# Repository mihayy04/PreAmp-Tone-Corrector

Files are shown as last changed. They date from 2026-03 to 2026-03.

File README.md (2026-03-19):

# Audio Preamplifier & Tone Corrector PCB 🎛️

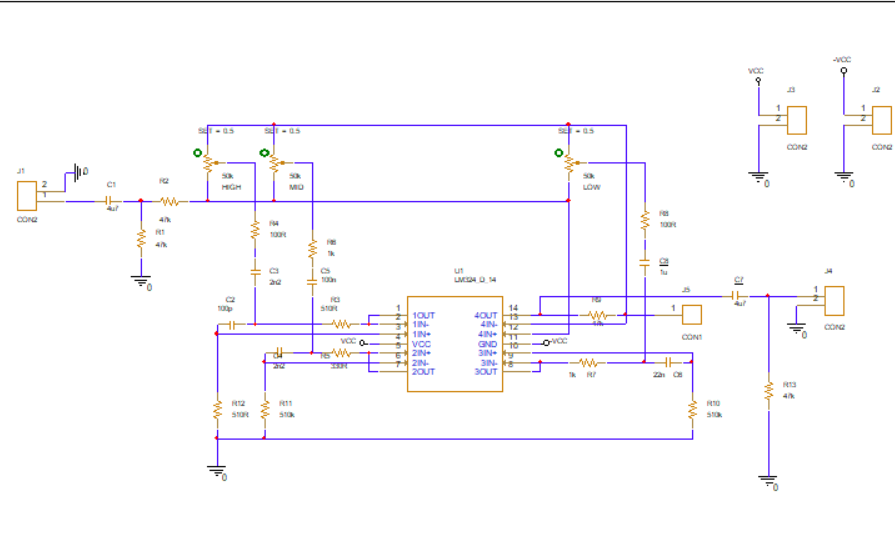
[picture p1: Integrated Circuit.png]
Integrated Circuit Render


## 📌 Project Overview
This repository contains the complete hardware design for an audio preamplifier featuring a dual-band tone corrector and an integrated linear power supply. The entire project—from schematic capture and SPICE simulations to PCB layout—was developed using **Cadence OrCAD**.

The circuit is built using discrete components and is designed to provide high-quality audio signal amplification with precise control over low and high frequencies[cite: 309, 313].

## 🚀 Key Features
* **Active Tone Control:** Independent attenuation and amplification (20dB) for bass (<500Hz) and treble (>1kHz) frequencies using an RC feedback network[cite: 311, 314, 327].
* **Discrete Analog Design:** The audio path and power regulation are built around classic Bipolar Junction Transistors (BC109C, BC107, BD135).
* **Integrated Linear Power Supply:** An on-board 25V regulated power supply featuring a series pass transistor and an error amplifier, ensuring a stable and low-noise power delivery for the audio stages.
* **Manufacturing Ready:** Includes full documentation, BOM, and manufacturing tables for immediate PCB fabrication.

## 📂 Repository Structure
The project files are organized to reflect a standard hardware engineering workflow:

* `📂 Bill of materials/` - Comprehensive BOM listing all components required for assembly.
* `📂 Data Sheet/` - Technical datasheets for the active and passive components used in the design.
* `📂 Layout/` - OrCAD PCB Editor files containing the board routing and layout data.
* `📂 Project docs/` - Detailed technical documentation, including mathematical component sizing and design choices.
* `📂 Schematics/` - OrCAD Capture schematic files for the preamplifier and power supply modules.
* `📂 Simulations/` - PSpice simulation results, including:
  * DC Operating Point (Bias) analysis.
  * Transient response analysis.
  * AC Sweep (Frequency response / Bode plots) demonstrating the tone correction curves.
* `📄 PCB_Manufacturing_Table_2026.docx` - Manufacturing specifics and tolerances.

## 💻 Software Stack
* **Cadence OrCAD Capture** (Schematics)
* **Cadence OrCAD PCB Editor** (Layout)
* **OrCAD PSpice** (Analog Circuit Simulation)

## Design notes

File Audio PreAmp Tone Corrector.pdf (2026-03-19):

### Capitolul 3

### PREAMPLIFICATOR AUDIO CORECTOR DE TON

În acest capitol este proiectat un preamplificator audio cu posibilitatea corecţiei frecvenţelor joase şi a celor înalte. Preamplificatorul audio corector de ton este compus din două etaje de amplificare conectate prin intermediul unei reţele de reacţie. Prin introducerea unor componente variabile în reţeaua de reacţie se pot amplifica sau atenua frecvenţele joase respectiv frecvenţele înalte.

### 3.1 TEMA DE PROIECTARE

Tema de proiectare se referă la proiectarea unui preamplificator audio corector de ton care să fie realizat cu tranzistoare bipolare. Corecţia de ton se referă la corecţia frecvenţelor joase şi anume a frecvenţelor mai mici ca 500Hz şi a frecvenţelor înalte respectiv mai mari ca 1KHz.
Etajul este compus din două amplificatoare, respectiv amplificatorul de intrare şi amplificatorul de ieşire, cuplate prin intermediul reţelei de reacţie de tipul RC. Reţeaua de reacţie este constituită din două filtre cu elemente pasive RC de joasă, respectiv înaltă frecvenţă în care anumite rezistenţe sunt variabile fapt ce permite amplificarea sau atenuarea frecvenţelor care sunt în banda de trecere a filtrelor RC. Amplificatorul de intrare şi cel de ieşire sunt alimentate din sursa de alimentare comună.

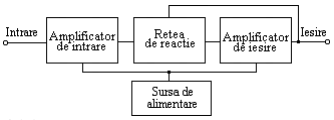
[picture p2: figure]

Figura 3.1-1. Schema bloc a preamplificatorului audio corector de ton

Preamplificator audio corector de ton | 71

### 3.2 SETURI DE DATE DE INTRARE

Principalii parametri ai preamplificatorului audio corector de ton sunt: Rezistenţa de intrare Ri (K )
Rezistenţa de ieşire Ro ( )
Corecţia minimă a frecvenţelor joase şi a frecvenţelor înalte 20dB

Sursa de alimentare va asigura următorii parametri:
Curentul nominal maxim I0M (mA)
Rezistenţa de ieşire maximă R0M ( )

Coeficientul de stabilizare
S
V

V
S

I
0min
0

0

Tensiunea de alimentare este 220Vac 10%

Tabelul 3.2-1. Seturi de date de intrare pentru proiectare
Nr. | Preamplificator corector de ton | Sursa de alimentare
Ri (M ) | Ro ( ) | Av (-) | Aî,j ( dB) | I0M (mA) | R0M ( ) | S0min (-)
1 | 2 | 150 | 5 | 20 | 10 | 3 | 2
2 | 2 | 150 | 5 | 18 | 10 | 4 | 3
3 | 2 | 150 | 5 | 16 | 10 | 5 | 4
4 | 2 | 150 | 5 | 14 | 10 | 6 | 5
5 | 2 | 150 | 5 | 12 | 10 | 7 | 6
6 | 2 | 150 | 4 | 20 | 10 | 3 | 2
7 | 2 | 150 | 4 | 18 | 10 | 4 | 3
8 | 2 | 150 | 4 | 16 | 10 | 5 | 4
9 | 2 | 150 | 4 | 14 | 10 | 6 | 5
10 | 2 | 150 | 4 | 12 | 10 | 7 | 6
11 | 2 | 150 | 3 | 20 | 10 | 3 | 2
12 | 2 | 150 | 3 | 18 | 10 | 4 | 3
13 | 2 | 150 | 3 | 16 | 10 | 5 | 4
14 | 2 | 150 | 3 | 14 | 10 | 6 | 5
15 | 2 | 150 | 3 | 12 | 10 | 7 | 6
16 | 2 | 150 | 2 | 20 | 10 | 3 | 2
17 | 2 | 150 | 2 | 18 | 10 | 4 | 3
18 | 2 | 150 | 2 | 16 | 10 | 5 | 4
19 | 2 | 150 | 2 | 14 | 10 | 6 | 5
20 | 2 | 150 | 2 | 12 | 10 | 7 | 6

72 | Proiectarea circuitelor electronice de audiofrecvenţă

Setul de date utilizate pentru exemplificare

Pentru proiectarea etajelor amplificatorului audio de putere a fost utilizat setul de parametri următori:

Tabelul 3.2-2. Setul de date utilizate pentru exemplificare
Nr. | Preamplificator corector de ton | Sursa de alimentare
Ri (M ) | Ro ( ) | Av (-) | Aî,j ( dB) | I0M (mA) | R0M ( ) | S0min (-)
1 | 2 | 150 | 5 | 20 | 10 | 3 | 2

### 3.3 SCHEMA ELECTRONICĂ

Conform schemei de principiu primul etaj este amplificatorul de intrare care asigură separarea reţelei de reacţie de etajele anterioare. În acest scop etajul de intrare este realizat cu tranzistorul T1 şi este de tip colector comun cu bootstrap la intrare asigurând o impedanţă mare de intrare şi mică de ieşire.
Reţeaua de reacţie este de tip RC cu elemente rezistive variabile P1 şi P2 care asigură reglarea frecvenţelor înalte şi joase.
Amplificatorul de ieşire este realizat cu tranzistoarele T2 şi T3 în conexiune emitor comun respectiv colector comun cuplate galvanic.
Primul etaj realizat cu T2 este destinat realizării unei amplificări de tensiune în buclă deschisă suficient de mare iar etajul realizat cu T3 este repetor pe emitor şi asigură o rezistenţă de ieşire mică. Cele două etaje realizează un amplificator inversor, astfel reţeaua de reacţie este plasată între intrarea şi ieşirea acestui amplificator de ieşire.

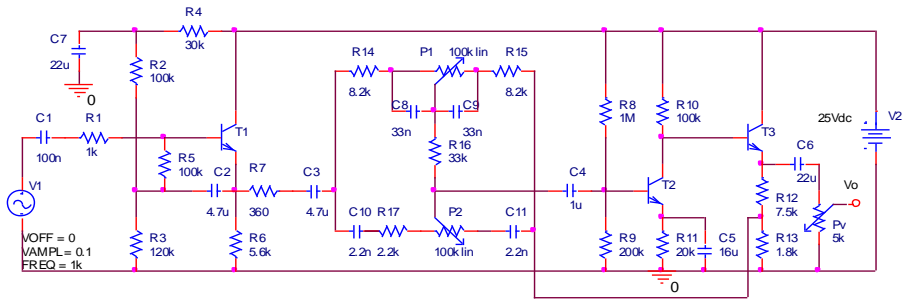
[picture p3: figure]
100k lin; 25Vdc; FREQ = 1k; VAMPL = 0.1; VOFF = 0

Figura 3.3-1. Schema electronică

Preamplificator audio corector de ton | 73

### 3.4 DIMENSIONAREA REŢELEI DE REACŢIE

Elementele de atenuare pozitivă sau negativă pentru frecvenţele înalte respectiv joase formează reţeaua de reacţie negativă.
Pentru o bună înţelegere a principiului de funcţionare a corecţiei amplitudinii pe anumite domenii de frecvenţă considerăm etajele amplificatoare echivalente cu circuite operaţionale care au conectate impedanţele echivalente ca în Figura 3.4-1..

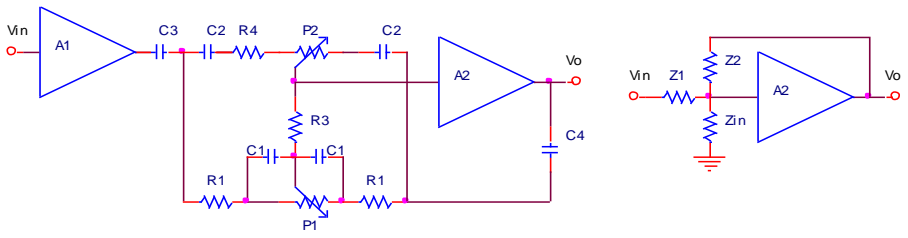
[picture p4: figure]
Zin; Vin

a) b)
Figura 3.4-1. Schema echivalentă a preamplificatorului audio corector de ton cu reţeaua de reacţie a) şi schema echivalentă simplificată b)

A1 reprezintă preamplificatorul de intrare iar A2 reprezintă amplificatorul de ieşire. Reţeaua de reacţie prevăzută cu potenţiometrele P1 şi P2 este desenată simplificat

în Figura 3.4-1. b), amplificarea etajului fiind data de raportul impedanţelor
Z

Z

1

2

Calculul reţelei de reacţie se face pentru circuitele echivalente la joasă şi înaltă frecvenţă.

Circuitul echivalent pentru înaltă frecvenţă

(1-a)P2

1k

R1 | R1

R1'

C2

R1' | R1'

aP2

1k

R4 | C2

R1'

R1

aP2

1k

(1-a)P2

1k

C2 | R4 | C2

R3

2R3 | 2R3

R1

Figura 3.4-2. Circuitul echivalent al reţelei de reacţie pentru înaltă frecvenţă

Pentru înaltă frecvenţă circuitul echivalent este prezentat în Figura 3.4-2., iar funcţia de transfer este:

F(p) =
Z

Z

1

2
= k
(1 | )(1 | )
(1 | )(1 | )
| 3 | 4
1 | 2
p t | p t
p t | p t

74 | Proiectarea circuitelor electronice de audiofrecvenţă
k = 1 | R1’ = R1 + 2R3
t1 = aR2C2 | t2 = [R1’ + (1-a)R2]C2
t3 = R1’C2 | t4 = R2C2

Curba de atenuare maximă se obţine pentru a = 0 şi rezultă:

t1 = 02 | t2 = [R1’ + R2]C2
t3 = (R1’+ aR2)C2 | t4 = (1-a)R2C2

Se alege P2 de 100K .
Pentru ca interferenţa celor două circuite să fie minimă se impune ca R1 | P2 şi
rezultă R1 | 10K .
R1’ s-a obţinut prin transformarea stelei R3, R1, R1 şi s-a neglijat rezistenţa ce apare între intrarea şi ieşirea lui A2, considerând că amplificatoarele A1 şi A2 au impedanţa de ieşire foarte mică.

Se alege f2 = 500Hz şi rezultă t2 = (R1’+R2)C2 = 3,2 10⁻⁴
s

Se alege f4 = 700Hz şi rezultă t4 = R2C2 2,3 10⁻⁴
s

Rezultă şi se adoptă C2 = 2,2nF.

Se alege f3 = 1KHz şi rezultă t3 = R1’C2 = 1,6 10⁻⁴
s,
R1’ = 72K .

Punctul f3 = 1KHz s-a dedus grafic pe caracteristica Bode astfel încât atenuarea teoretică de –20dB se produce la 15KHz.

Se alege R1 = 8,2K şi R3 =
2

1

'
R1 R
= 31,9K .

Se adoptă R3 = 33K .

Curba de ridicare minimă se obţine pentru a = 1 şi rezultă:
t1 = R2C2 | t2 = R1’ C2
t3 = (R1’+R2)C2 | t4 = R4C2

Curba de ridicare va fi simetrică cu cea de coborâre până la f4, când factorul de transfer devine constant.
Astfel, se explică rolul rezistenţei R4 care menţine al doilea pol din funcţia de transfer, chiar pentru a = 1 asigurându-se stabilitatea.
Se apreciază din considerente practice confirmate experimental că f4 | 30Hz | t4

= (2 f4)

-1
= 5,3 | R4 =
C

t

2

4
= 2,4K

Preamplificator audio corector de ton | 75

Circuitul echivalent pentru joasă frecvenţă

C1

R1 | aP1 | (1-a)P1 | R1

C1

Figura 3.4-3. Circuitul echivalent pentru joasă frecvenţă

Pentru circuitul echivalent la joasă frecvenţă funcţia de transfer are forma:

F(p) =
Z

Z

1

2
= k
(1 | )(1 | )
(1 | )(1 | )
| 3 | 4
1 | 2
p t | p t
p t | p t
Se alege | P1 = nR1 = 100K | n 12

Curba de atenuare maximă se obţine pentru a = 0

k = | 1 n

1
| ,
t1 = 0 | | t2 = n R1 C2
t3 = 0 | | t4 =
n 1

n
R1 C2

Curba de ridicare maximă se obţine pentru a = 1 k = n + 1,
t1 = | n 1 n
| R1 C1 | t2 = 0
t3 = n R1 C1 | t4 = 0
Se alege | f2 = 50Hz | t2 = 3,2s
| C1
| R

t

1

2
12

= 32nF Se adoptă C1 = 32nF.

Reţeaua pentru joasă frecvenţă începe să lucreze sub frecvenţa de aproximativ 500Hz. La 50Hz ridicarea este de 20log(n +1)=22dB iar atenuarea de –22dB.

### 3.5 PROIECTAREA AMPLIFICATORULUI DE IEŞIRE

Amplificatorul de ieşire A2 este realizat cu T2 şi T3 iar pentru respectarea condiţiei de semnal mic trebuie ca semnalele alternative să fie mult mai mici ca tensiunea de alimentare. O tensiune de alimentare mare implică şi rezistenţe de polarizare de valori mari şi deci impedanţă mare de intrare. Din aceste considerente se alege Ec = 25V stabilizată. Distorsiunile se vor măsura experimental şi se va modifica PSFul dacă este cazul.

76 | Proiectarea circuitelor electronice de audiofrecvenţă
1. Se alege PSFul pentru tranzistorul T2

Curentul de colector ICT2 =0,1mA şi tensiunea colector-emitor VCE2 10V

Se alege raportul
R

R

11

10
10
Se alege VR10 | 10V | Se adoptă R10 = 100K şi R11 =20 K
2. Se alege PSFul pentru tranzistorul T3

Curentul de colector ICT3 =1,5mA şi tensiunea colector-emitor VCE3 = 10V

R12 + R13
I
E | V
| C
C | CE

3

3
=
1,5mA

15V
= 10K
3. Alegerea tranzistoarelor

Se aleg tranzistoarele de tip BC109C cu următoarele valori limită absolute:
VCE0 =25V | IC = 100mA | IB = 50mA
Ptot = 300mW | Tj = 175 C
şi caracteristicile statice:
h21E = 270 | VCEsat | 0,2V | VBEsat | 0,8V
4. Dimensionarea rezistenţelor R12, R13

IB,T3 =
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
1,5mA
= 5,5 A

Acest curent poate fi neglijat în raport cu IC2. În acest caz tensiunea pe R10 este: VR10 = R10 IC2 = 100K 0,1mA = 10V
VR12+R13 = EC – VR10 – VBE2 = 25 – 10 - 0,6 = 14,4V
În reţeaua de reacţie s-a neglijat rezistenţa care apare între intrarea şi ieşirea amplificatorului de ieşire A2. Valoarea acestei rezistenţe este:

Rp =
| R
R | R R

3

1 3

2
1 | 2
18K | R0,A2

Se alege R13 = 1,8K şi se calculează R12:

R12 + R13 =
I

V

C

R | R
| 3
12 | 13
=
mA

V
1,5

14,4
= 9,3K

R12 = 9,3K - 1,8K = 7,5K .

5. Calculul divizorului de bază pentru tranzistorul T2

Curentul prin divizorul de polarizare a bazei tranzistorului T2 este:

IB2 =
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
0,1mA
= 0,37 A

Preamplificator audio corector de ton | 77

Deoarece impedanţa de intrare a amplificatorului A2 este dată de impedanţa de intrare în T2, iar aceasta este aproximativ R9, se alege R9 = 200K .
Tensiunea pe rezistenţa R9 poate fi exprimată astfel:
VR9 = VR11 +VBE2 = 20K | 0,1mA + 0,6V = 2,6V
R | R

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
R8 8R9 = 1,6M

6. Calculul impedanţei de intrare în A2

Parametri dinamici ai tranzistorului T2 sunt:

gm2 = 40 IC2 = 40 0,1 = 4mA/V

h11e,T2 =
| gm2 =
4

270
= 67,5K

Impedanţa de intrare în T2 este:

Zin, T2 = h11e,T2 + h21e,T2 | R11 = 67,5 K + 270 20K | 5,4M

Impedanţa de intrare în T2 este:

Zin, A2 = ( R9 | R8 ) Zin, T2 | 180K | 5,4M | 180K
Această valoare este suficient de mare.
7. Amplificarea în buclă deschisă a etajului realizat cu T2

Atenuarea maximă a circuitului este de aproximativ 10 şi se verifică ca amplificarea fără reacţie să fie suficient de mare:

Av | Av,T2 =
R | h
h | R
g | e
E | S
| 11 2
21 | 2

RS2 este rezistenţa de sarcină a tranzistorului T2:

RS2 = R10 Zin, T3

Zin, T3 = h11e3 + h21e3 (R12 +R13) =
40 1,5mA

270
+ 270 9,3K | 2,5M
RS2 | R10 = 100K
Av | Av,T2 =
K

K
80

270 100
= 338 valoare suficient de mare.
8. Amplificarea în buclă închisă

În poziţia mediană a lui P1 şi P2 se obţine Z1 = Z2, iar amplificarea este:

78 | Proiectarea circuitelor electronice de audiofrecvenţă

Avr

r

1
=
R
R | R
| 13
12 | 13
=
1,8

7,5 1,8
= 5,17 5

Micşorarea amplificării este compensată de îmbunătăţirea răspunsului tranzitoriu.

9. Dimensionarea condensatorului C5

C5 formează un pol şi un zero, polul fiind plasat la frecvenţă mai mare.

5 =

h

R h
C R
| e
g | e

21 2

11 2
5 11

1

Pentru tranzistorul T2, considerăm pentru uşurinţa calculelor parametri dinamici
aproximativi h11e2 | 100K şi h21e2 | 100.
Din motive de stabilitate se alege polul dat de C5 polul dominant al schemei şi anume f5=10Kz.

C5 =
| h h
f
| e

e

21 2

11 2
5

2

1
= 15,9 F

Se adoptă C5 = 16 F/10V

10. Dimensionarea condensatorului C4

Tot din considerente de stabilitate, se alege polul dat de C4 la o frecvenţă mult mai mică decât cea dată de C5. Se alege f4 = 1Hz 10Hz = f5.

C4 =
2 f
4 Zin,A2

1
=
2 1 180K

1
= 0,88 F

Se alege C4 = 1 F.

### 3.6 PROIECTAREA AMPLIFICATORULUI DE INTRARE

Amplificatorul de intrare este constituit din etajul repetor pe emitor cu bootstrap la intrare realizat cu tranzistorul T1.

1. Stabilirea PSFului

Se alege IC1 = 2mA care este o valoare relativ mare din punct de vedere al zgomotului, dar care asigură curent de bază suficient de mare pentru a fi insensibil la curentul de fugă prin capacitatea de bootstrap C2.
Se alege VCE1 | VR6.
Cunoaştem R6 şi IC1 | VR6 = 5,6K | 2mA = 11,2V

Preamplificator audio corector de ton | 79

VCE1 = EC - VR6 = 13,8V

2. Dimensionarea rezistenţei R5

Tensiunea în baza tranzistorului T1 este:
VBT1 = VBE1 + VR6 = 0,6 + 11,2 = 11,8V Curentul de bază al tranzistorului T1 este:

IBT1 =
h

I

E

C

21 1

1
=
400

2
= 5 A
Din catalog pentru IC1 = 2mA şi VCE1 = 14V se obţine h11e1 | 10K .
Se impune R5 | h11e1 şi se alege R5 = 100K .
VR5 = R5 | IB1 = 100K | 5 A = 0,5V
VR3 = VB1 + VR5 = 11,8 + 0,5 = 12,3V
3. Calculul divizorului de bază

Se alege Id = 20 IB1 = 100 A

R2 + R3 + R4 =
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
= 250K
R3 = | R | R | R
E

V

C

R
2 | 3 | 4

3
= | K
V

V
250
25

12,3
= 123K

Se adoptă R3 = 120K .
Pentru a avea o valoare convenabilă a condensatorului de filtraj C7 se alege R4 = 30K şi R2 = 100K .
4. Dimensionarea condensatorului de filtraj C7

Rezistenţa R4 şi condensatorul C7 decuplează alimentarea circuitului de bază. Pentru o bună decuplare f7 frecvenţa inferioară limită a benzii.

Pentru C7 = 22 F se obţine f7 =
2 C7 R4

1
= 0,24Hz
5. Impedanţa de intrare

Impedanţa de intrare în amplificatorul de intrare şi în preamplificatorul corector de ton este:
Zin = R5 h11e1 + ( ’
+ 1) R6

’
= 1
R h

R

5 11e1

5
= 400
K K

K
100 10

100
= 360

Zin = 9,1 K +360 5,6K = 2M

80 | Proiectarea circuitelor electronice de audiofrecvenţă
6. Dimensionarea condensatoarelor C1, C2

Condensatoarele C1 şi C2 se dimensionează pentru frecvenţe mai mici ca 1Hz. Se

alege C1 = 0,1 F şi se obţine f1 =
| 2 C1Zin
| 1 = 0,79Hz

Pentru C2 se alege f2 = 0,5Hz şi se obţine C2 =
| 2 f 2R5

1
= 3,2 F

Se adoptă C2 = 4,7 F

7. Impedanţa de ieşire a amplificatorului de intrare

Z0,A1
R
Zg | RS | h e

6 '

| | 11 1
| | 1
Se apreciază că impedanţa generatorului este mai mică decât 15K şi pentru cazul cel mai defavorabil se ia Zg = 15K .

Z0,A1

K

K K
5,6
360

15 9
6,6

Se verifică condiţia Z0,A1 = 6,6 Rp = 18K

8. Impedanţa de ieşire a preamplificatorului corector de ton
Z0, pct = | R | R
h
Z | h
| e
g | e
12 | 13
21 3

11 3

Zg = R10
h22e2

1
= 100K 92K = 48K

Considerăm pentru T3 parametri dinamici următori: h11e3 = 10K şi h21e3 = 400

Z0, pct = | K
K | K
9,3
400
| 48 | 10
= 143
9. Dimensionarea potenţiometrului de volum

Se poate face dimensionarea potenţiometrului de volum utilizând condiţia:

Z0, pct | Pv | Zin, AP
Impedanţa de intrare în amplificatorul audio de putere Zin, AP | 39K

Raportul impedanţelor limită este k =
Z

Z

pct

in AP

0,

,
=
143

39K
270

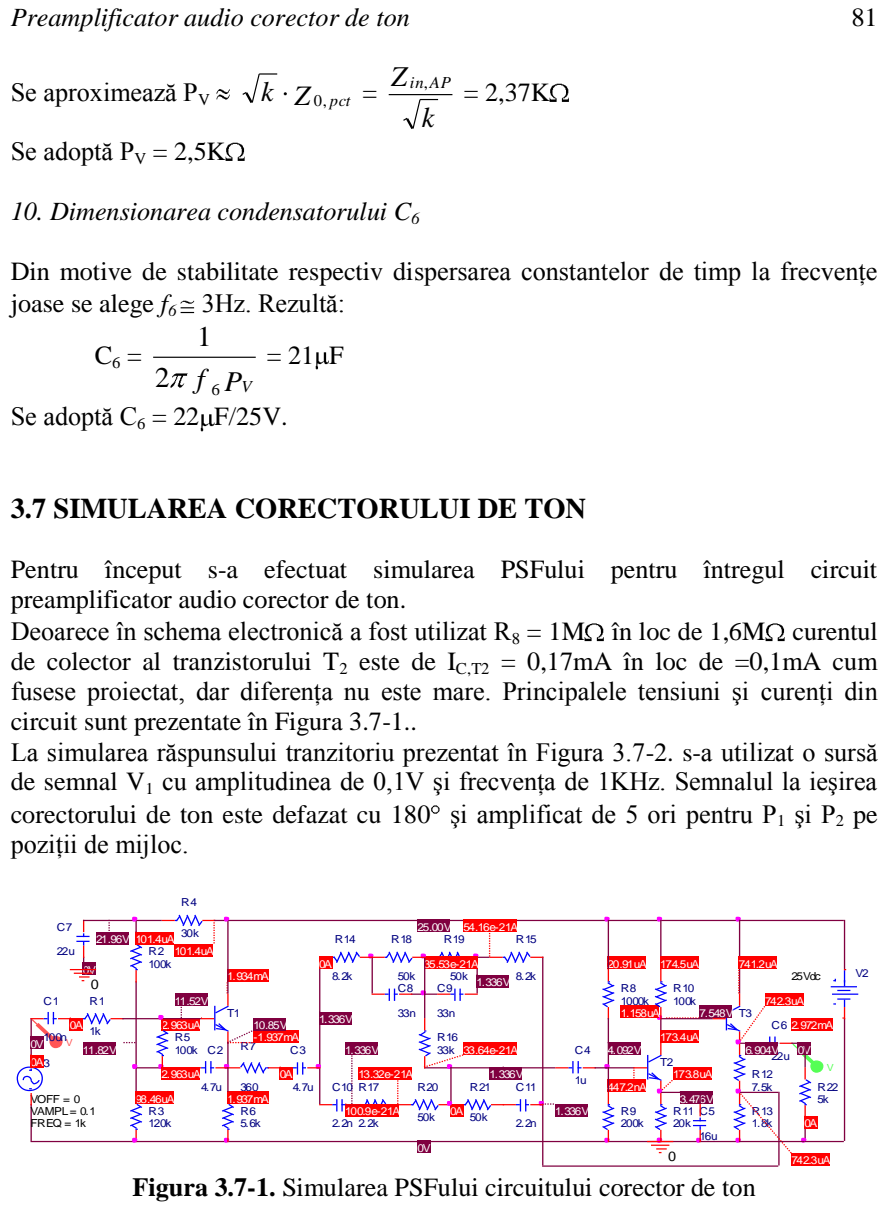
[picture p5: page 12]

Din motive de stabilitate respectiv dispersarea constantelor de timp la frecvenţe

3.7 SIMULAREA CORECTORULUI DE TON

Pentru început s-a efectuat simularea PSFului pentru întregul circuit
preamplificator audio corector de ton.
Deoarece în schema electronică a fost utilizat R8 = 1M în loc de 1,6M curentul
de colector al tranzistorului T2 este de IC,T2 = 0,17mA în loc de =0,1mA cum
fusese proiectat, dar diferenţa nu este mare. Principalele tensiuni şi curenţi din
circuit sunt prezentate în Figura 3.7-1..
La simularea răspunsului tranzitoriu prezentat în Figura 3.7-2. s-a utilizat o sursă
de semnal V1 cu amplitudinea de 0,1V şi frecvenţa de 1KHz. Semnalul la ieşirea
corectorului de ton este defazat cu 180 şi amplificat de 5 ori pentru P1 şi P2 pe
poziţii de mijloc.

Figura 3.7-1. Simularea PSFului circuitului corector de ton

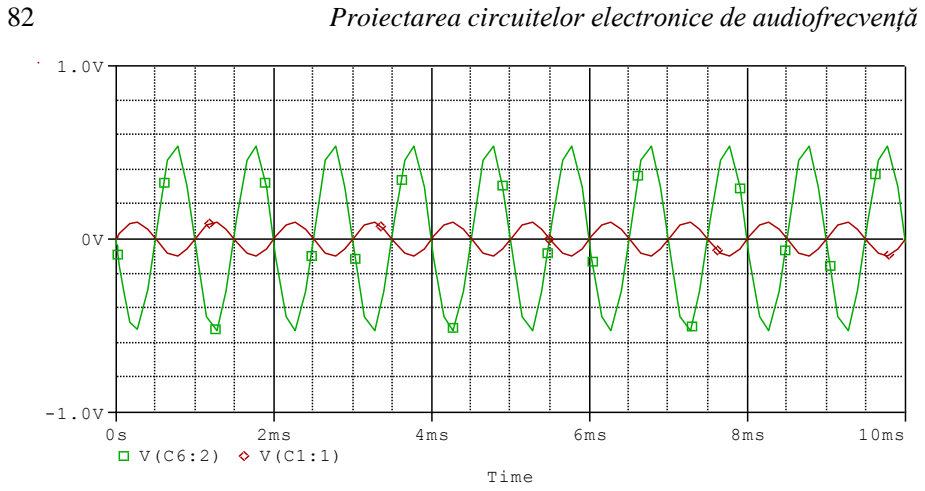
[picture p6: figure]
Proiectarea circuitelor electronice de audiofrecvenţă; Time

Figura 3.7-2. Simularea tranzitorie a circuitului corector de ton

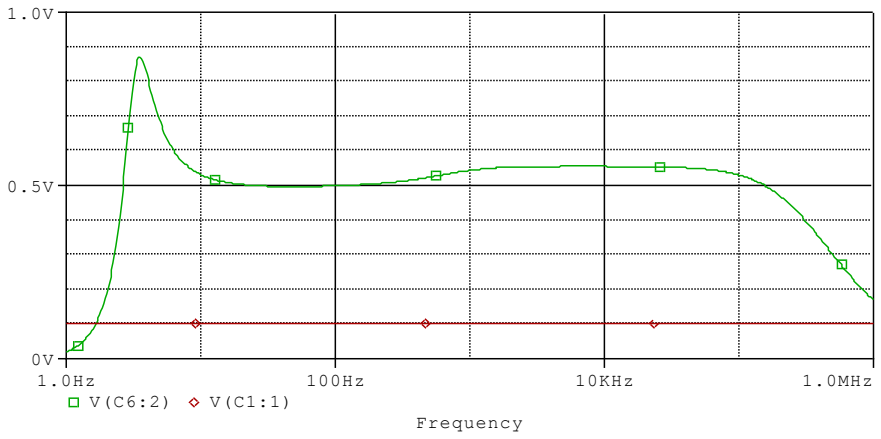
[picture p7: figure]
Frequency; 10KHz; 1.0MHz

Figura 3.7-3. Simularea răspunsului în frecvenţă al corectorului de ton cu P1 şi P2 pe poziţia mediană (R18=50K , R19=50K şi R20=50K , R21=50K )

Simularea răspunsului în frecvenţă pentru P1 şi P2 pe poziţii de mijloc Figura 3.7-
3. ne arată o amplificare de 5 la o amplitudine a semnalului de 0,1V şi răspuns uniform în banda de frecvenţe cu excepţia frecvenţelor joase unde este practic realizată o corecţie fiziologică.
Simulările 3.7-4. 3.7-7. arată accentuarea şi atenuarea frecvenţelor joase şi a celor înalte cu aproximativ 20dB faţă de poziţia mediană de la 0,5V.

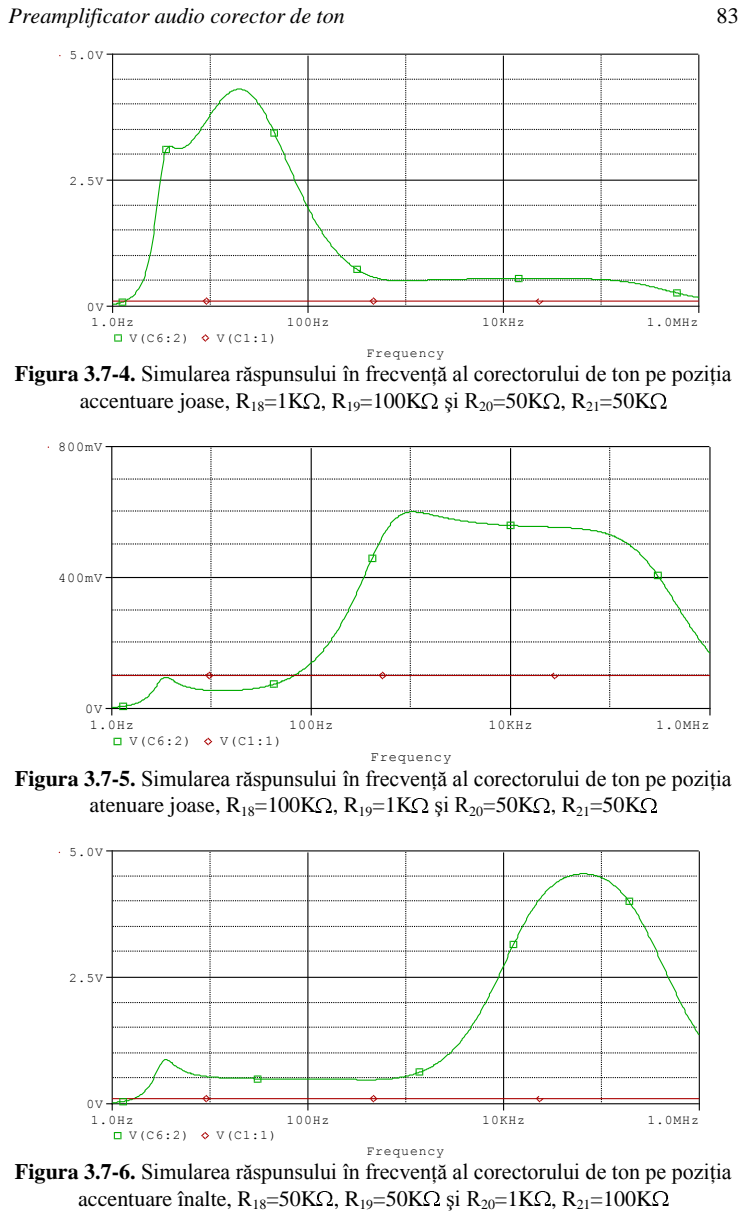
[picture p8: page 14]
Preamplificator audio corector de ton; Frequency; 10KHz; 1.0MHz

Figura 3.7-4. Simularea răspunsului în frecvenţă al corectorului de ton pe poziţia

accentuare joase, R18=1K , R19=100K şi R20=50K , R21=50K

Figura 3.7-5. Simularea răspunsului în frecvenţă al corectorului de ton pe poziţia

atenuare joase, R18=100K , R19=1K şi R20=50K , R21=50K

Figura 3.7-6. Simularea răspunsului în frecvenţă al corectorului de ton pe poziţia

accentuare înalte, R18=50K , R19=50K şi R20=1K , R21=100K

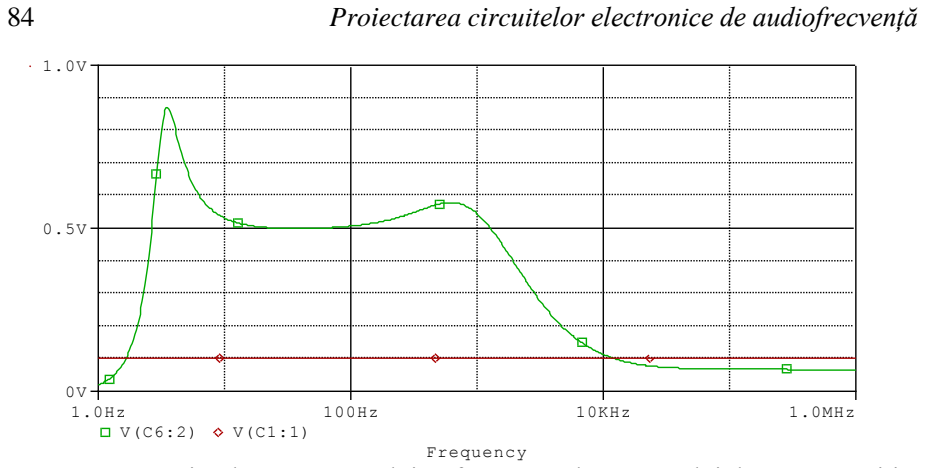
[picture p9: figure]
Proiectarea circuitelor electronice de audiofrecvenţă; Frequency; 10KHz; 1.0MHz

Figura 3.7-7. Simularea răspunsului în frecvenţă al corectorului de ton pe poziţia atenuare înalte, R18=50K , R19=50K şi R20=100K , R21=1K

### 3.8 SURSA DE ALIMENTARE

Alimentarea preamplificatorului audio corector de ton se face utilizând stabilizatorul din Figura 3.8-1. alcătuit dintr-un tranzistor regulator serie T1 şi un amplificator de eroare realizat cu tranzistorul T2. Diodele D1, D2 realizează o prestabilizare a tensiunii de alimentare a amplificatorului de eroare, iar dioda D3 realizează tensiunea de referinţă.
Conform temei de proiectare variaţiile tensiunii de alimentare sunt 10%. Pentru o tensiune medie la ieşirea redresorului VR=30V tensiunea maximă la ieşirea redresorului şi tensiunea minimă la ieşirea redresorului sunt VRM=33V şi VRm=27V.

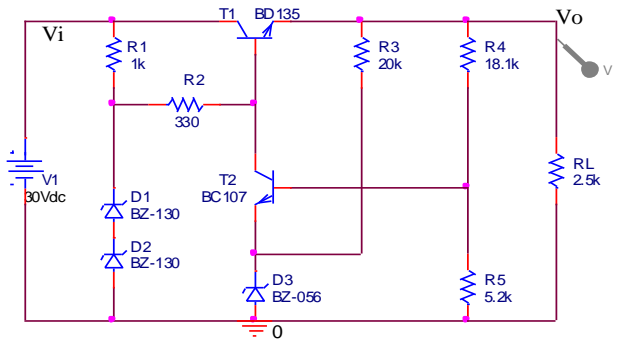
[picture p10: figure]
V1 30Vdc

Figura 3.8-1. Stabilizatorul pentru preamplificatorul audio corector de ton

Curentul de alimentare pentru două canale ale amplificatorului corector de ton cu tranzistoare se estimează la 2x3mA 10mA.
Tensiunea de ieşire a stabilizatorului este de 25Vcc.

Preamplificator audio corector de ton | 85

Proiectarea stabilizatorului

1. Alegerea tranzistorului regulator serie

Se alege tranzistorul T1=BD135 cu următorii parametri:
VCE0 = 80V | IC =1A | Ptot= 12,5W
VCER = 100V | ICM =1,5A | fT = 50MHz
VEB0 = 5V | IB =0,2A | Rthj-C | 10 C
h21E = 50 200 | Tj =150 C
PSFul tranzistorului T1 este IC=10mA, VCE=5V pentru care h21e | 100.
2. Alegerea diodelor stabilizatoareD1, D2

Se aleg diodele D1, D2 = BZ-130 care au următorii parametri:
RS = 0,001 | CJ0 = 1 10⁻¹² | | M = 0,3333
Vj = 0,75 | ISR = 3,997 10⁻⁶ | | BV = 13,05
IBV = 0,1293 | TT = 144,3 10⁻⁹

Curentul maxim prin diodă este IM =
BV

PM
| | = | V

mW
13

100
= 7,7mA, iar pentru

curentul minim se alege Im = 0,5mA IBV = 0,1293mA

Curentul din baza tranzistorului T1 este:

mA mA I
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
21 1

1

Din considerente de stabilitate a PSFului se alege curentul prin R2 mult mai mare ca IB1 respectiv IR2 0,7mA 0,1mA=IB1.

3. Dimensionarea rezistenţei R1

Dimensionarea rezistenţei R1 se face astfel ca la tensiunea de intrare minimă aceasta să asigure funcţionarea diodei zener la Im = 0,5mA IBV = 0,1293mA.

k
I | I | mA | mA

V
R
Z | R

0,84
0,5 | 0,7
| | 27 26
min | 2
| min
1 | , | Se adoptă R1=1K

În condiţiile în care tensiunea de intrare este maximă curentul prin dioda zener nu trebuie să depăşească curentul maxim admisibil.

I | mA | mA
| | K

I
R

V
I
Z | R | R | 7 | 0,7
1

33 26

2 | 2
1

max
max

= 6,3mA

IZ max = 6,3mA IMax adm = 7,7mA.

4. Dimensionarea rezistenţei R2

86 | Proiectarea circuitelor electronice de audiofrecvenţă

R2 =
I
V | V | V | V

R

D | D | BE

2

1 | 2 | 0 | 1
=
0,7

13 13 25 0,7
=
mA

V
0,7

0,3
=428

Se adoptă R2 =330

5. Verificarea puterii disipate de tranzistorul regulator serie T1

Pentru verificarea puterii disipate de T1 în cazul cel mai defavorabil calculăm tensiunea colector-emitor, când prin diodele D1, D2 trece curentul maxim de 7,7mA. În această situaţie tensiunea pe rezistenţa R1 esteVR1=7,7V iar tensiunea pe rezistenţa R2 este VR2=0,7mA 0,33K = 0,23V. Deoarece VCB=VR1+VR2 VCE=VR1+VR2 +VBE=8,63V
Pd = VCE IC = 8,63V 10mA=86,3mW Puterea disipată fără radiator=2W.
6. Alegerea diodei stabilizatoare D3

Se alege dioda D3 = BZ-056 care are următorii parametri:
RS = 0,001 | CJ0 = 1 10⁻¹² | M = 0,3333
Vj = 0,75 | ISR = 7,539 10⁻⁶ | BV = 5,009
IBV = 0,04311 TT = 144,5 10⁻⁹

Curentul maxim prin diodă este IM =

| BV PM
=
V

mW
5

100
= 20mA, iar pentru curentul

minim se alege Im = 1mA IBV = 0,04311mA

7. Dimensionarea rezistenţei R3

R3 =
I
V | V
| m
0 | D3
=
mA

V
1

20
= 20K
8. Dimensionarea rezistenţelor R4, R5

Căderea de tensiune pe rezistenţa R5 este:

VR5 = V0
R R

R

5 | 4

5
= (VZD3 + VBE2)

R4 = R5
1
3 | 2

0
V V

V

ZD | BE

= 3,386R5

Se alege curentul prin divizorul format de R4 şi R5 de aproximativ 1mA şi R4
=18,1K | R5 =5,2K
9. Alegerea tranzistorului T2

Se alege tranzistorul T2=BC107 cu următorii parametri:
VCE0 = 45V | IC =100mA | Ptot= 300mW

Preamplificator audio corector de ton | 87
VCER = 50V | VEB0 = 6V | IB =50mA
fT = 250MHz | Rthj-C | 200 C | h21E = 90

Tj =175 C

PSFul tranzistorului T2 este IC2 1mA şi VCE2=V0+VBE1-VZD3=25+0,7-5 = 25,7-5 = 20,7V.
Puterea disipată de tranzistorul T2 este:
Pd = VCE2 | IC2 = 20,7V 1mA=20,7mW | 300mW.
10. Randamentul stabilizatorului

Curentul de intrare în stabilizator este:
II = I0 + IDZ1,DZ2 + IR2 + IDZ3 + IR4,R5 = 10+3,4+0,7+1+1=16,1mA

=
V I

V I

I | I
0 | 0
=
30 16,1

25 10
=0,52 | = 52%
11. Rezistenţa de ieşire a stabilizatorului

Parametrii de regim alternativ ai tranzistoarelor sunt:

T1
h K g

h

g | I | mA V

e

m

ie

m | C

1

250
400

100

40 | 400 | /

1
0 1

1

1

1 | 1

T2,

h

K
g

h

g | I | mA V

e

m

ie

m | C

1
0

2,5
40

100

40 | 40 | /

Calculul rezistenţei de ieşire se face considerând intrarea referinţa de tensiune şi tratând stabilizatorul ca un amplificator cu reacţie negativă ca în Figura 3.8-2..

T2

R5

ro

R4

R2 | RL

R4 II R5

Rz3 | D Vf

D Vzo

0

D Vz3

T1

Figura 3.8-2. Circuitul de curent alternativ cu VZ3 la intrare

av =
V

V

Z 3

0
=
R | R
R | R
Z | i T i T
3 | , 2
2 | , 1
=

1

1

2

2 | 4 | 5
3

1
2 | , 1 | 1 | 4 | 5 | 0 1

h

h | R | R
R
R | h | h | R | R | R | h

fe

ie
Z
i e | fe | L | e
= 5

Transmisia circuitului de reacţie negativă serie la intrare şi paralel la ieşire alcătuită din R4, R5 este:

88 | Proiectarea circuitelor electronice de audiofrecvenţă

fV =

R | R R
5 | 4
| 5 =
| 23,3
| 5,2 =0,22

Transmisia pe buclă este:
T = aV fV = 5 0,22 = 1,1
Rezistenţa de ieşire în buclă deschisă este:
r0 | R0,T1 | R4 | R5 | = | R | R
h

R h

fe

ie
4 5
1
2 | 1
1

= 5,7

Rezistenţa de ieşire cu reacţie este:

T

r
R
1

0
0

= 2,7

12. Coeficientul de stabilizare cu tensiunea

Calculul coeficientului de stabilizare se face pe circuitul din Figura 3.8-3..

T1 | D Vo

R4+R5

R1

D Vi1

1/hoe1

R2

Rz1,z2

0

D Vi2

0
Figura 3.8-3. Circuitul pentru calculul coeficientului de stabilizare

V

V

I

0
=
R | R | h
| R | R
| | e

1
4 | 5 | 0 1
| 4 | 5
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
, 1 2

, 1

1, 2 1

1, 2
=
R | R | h
R | R

e

1
4 | 5 | 0 1
4 | 5
+
R | h | h | R | R
h | h | R | R
R | R

R

ie | fe
ie | fe

Z Z

Z Z

2 | 1 | 1 | 4 | 5
1 | 1 | 4 | 5
1, 2 | 1

1, 2
1

1
=0,96

S0 =
T

V I

V

1

0

1

= 2,2

13. Simularea stabilizatorului

Simularea stabilizatorului s-a făcut pentru o tensiune de intrare de 30Vcc din punct de vedere al punctului static de funcţionare Figura 3.8-4. şi cu baleiajul tensiunii de intrare în domeniul VI = 1 40Vcc în figura 3.8-5..

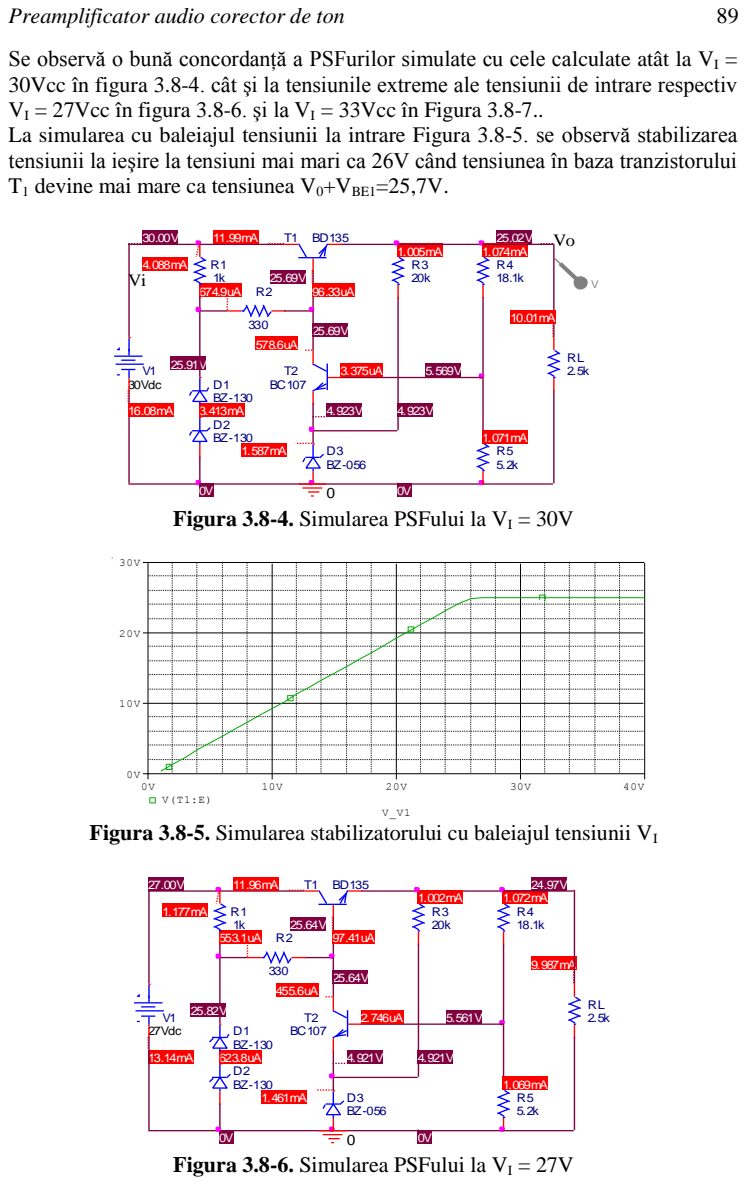
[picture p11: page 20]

Se observă o bună concordanţă a PSFurilor simulate cu cele calculate atât la VI =
30Vcc în figura 3.8-4. cât şi la tensiunile extreme ale tensiunii de intrare respectiv
VI = 27Vcc în figura 3.8-6. şi la VI = 33Vcc în Figura 3.8-7..
La simularea cu baleiajul tensiunii la intrare Figura 3.8-5. se observă stabilizarea
tensiunii la ieşire la tensiuni mai mari ca 26V când tensiunea în baza tranzistorului
T1 devine mai mare ca tensiunea V0+VBE1=25,7V.

Figura 3.8-4. Simularea PSFului la VI = 30V

Figura 3.8-5. Simularea stabilizatorului cu baleiajul tensiunii VI

Figura 3.8-6. Simularea PSFului la VI = 27V

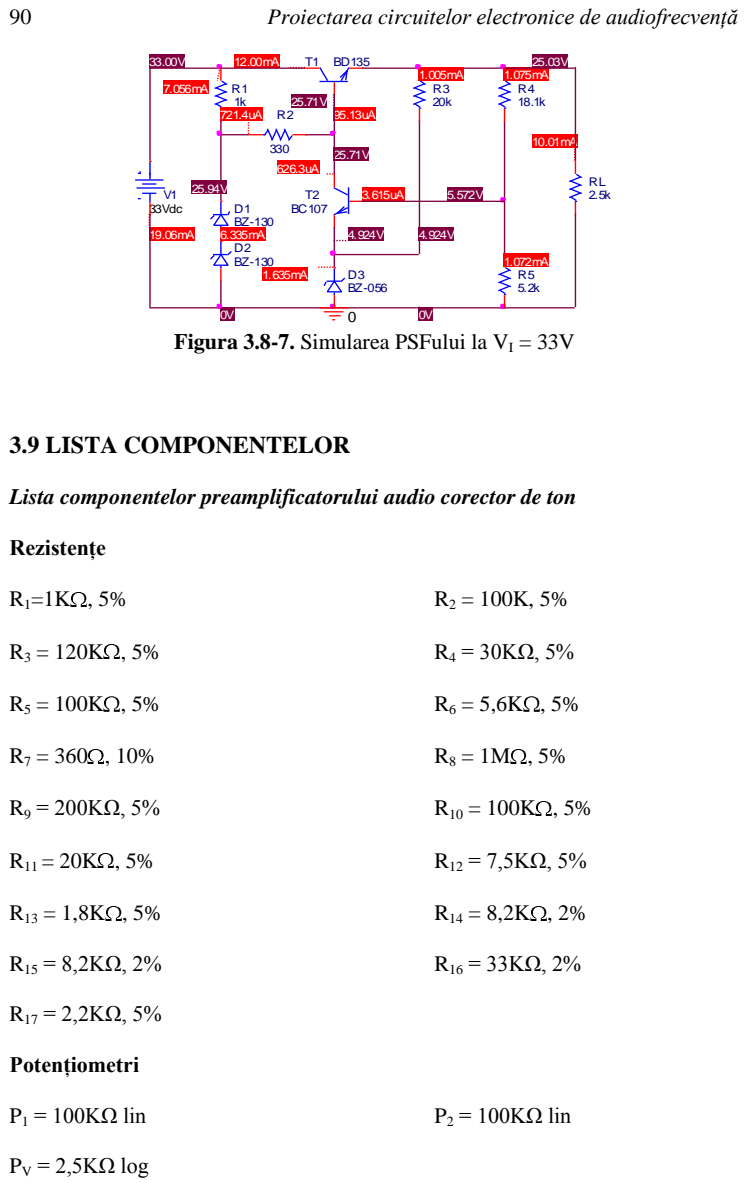
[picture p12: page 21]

Figura 3.8-7. Simularea PSFului la VI = 33V

Lista componentelor preamplificatorului audio corector de ton

Preamplificator audio corector de ton | 91

Condensatori

C1 = 0,1μF/10V | C2 = 4,7μF/10V
C3 = 4,7μF/10V | C4 =1μF/10V
C5 = 16μF/10V | C6 = 22μF/25V
C7 = 22μF/25V | C8 = 33nF, 5%
C9 = 33nF, 5% | C10 = 2,2nF, 5%

C11 = 2,2nF, 5%

Tranzistori

T1 = BC 109C | T2 = BC 109C

T3 = BC 109C

EC = 25V

Lista componentelor stabilizatorului

Rezistenţe

R1=1K , 5% | R2 = 330 , 5%
R3 = 20K , 5% | R4 = 18,1KΩ, 5%

R5 = 5,2K , 5%

Tranzistori

T1 = BD 135 | T2 = BC 107

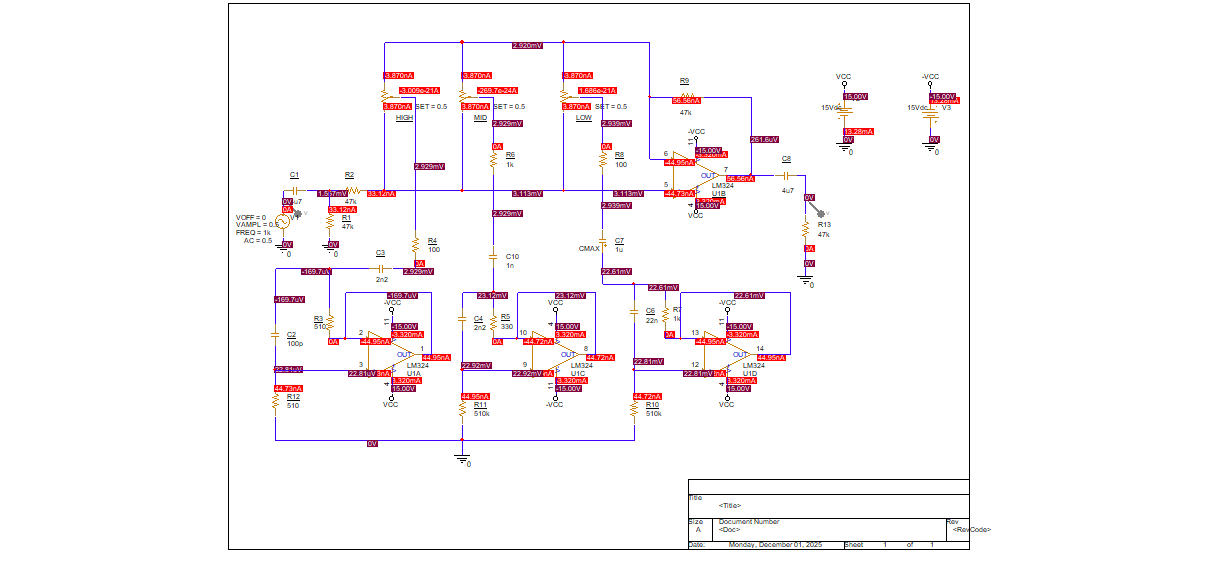
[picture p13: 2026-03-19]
Schematics/ISPAS_MIHAI_ORCAD.png

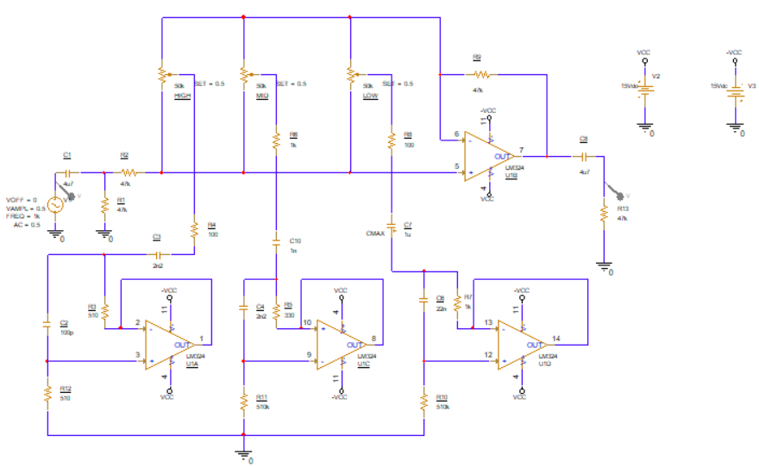
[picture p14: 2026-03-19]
Schematics/Circuit.png

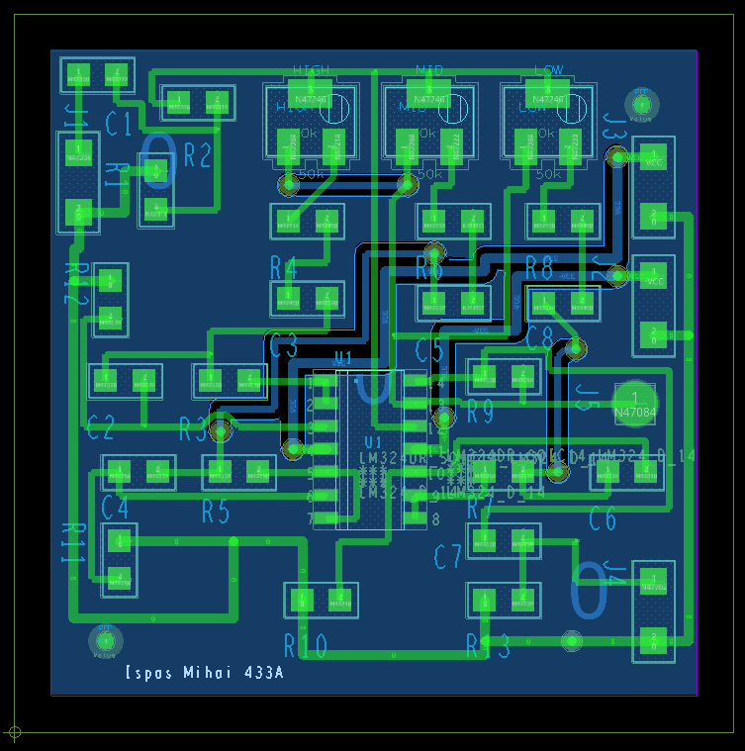
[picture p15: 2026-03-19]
Layout/Layout.png

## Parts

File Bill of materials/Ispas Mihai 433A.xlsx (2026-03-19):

 |  |  | Cantitate
AO | (LINK) (https://www.tme.eu/ro/details/lm324dr/amplificatori-operationali-smd/texas-instruments/) | LM324DR | 1
4.7uF | (LINK) (https://www.tme.eu/ro/details/cl21a475kaqnnng/condensatoare-mlcc-smd-0805/samsung/) | CL21A475KAQNNNG | 2
100p | (LINK) (https://www.tme.eu/ro/details/cl21b104kbcnnnc/condensatoare-mlcc-smd/samsung/) | CL21B104KBCNNNC | 1
2.2nF | (LINK) (https://www.tme.eu/ro/details/cl21b222jbannnc/condensatoare-mlcc-smd-0805/samsung/) | CL21B222JBANNNC | 2
100nF | (LINK) (https://www.tme.eu/ro/details/cl21b104kbcnnnc/condensatoare-mlcc-smd/samsung/) | CL21B104KBCNNNC | 1
22nF | (LINK) (http://www.tme.eu/ro/details/cl21b223kcfnnne/condensatoare-mlcc-smd-0805/samsung/) | CL21B223KBANNNC | 1
1uF | (LINK) (https://www.tme.eu/ro/details/cl21b105kbfnnng/condensatoare-mlcc-smd-0805/samsung/) | CL21B105KBFNNNG | 1
50k | (LINK) (http://www.tme.eu/ro/details/3314g-1-503e/trimere-smd-cu-o-singura-tura/bourns/) | 3314G-1-503E | 3
Conn2p | (LINK) (http://www.tme.eu/ro/details/zl301-40p/pini-cu-benzi-si-soclu/ninigi/) | ZL301-40P | 4
CON1* |  |  | 1 | Lipseste din anexa
47k | (LINK) (http://www.tme.eu/ro/details/smd0805-47k/rezistente-smd-0805/royal-ohm/0805s8j0473t5e/) | SMD0805-47K-5% | 4
510 | (LINK) (https://www.tme.eu/ro/details/smd0805-510r/rezistente-smd-0805/royal-ohm/0805s8j0511t5e/) | SMD0805-510R-5% | 2
100 | (LINK) (https://www.tme.eu/ro/details/smd0805-100r/rezistente-smd-0805/royal-ohm/0805s8j0101t5e/) | SMD0805-100R-5% | 2
330 | (LINK) (https://www.tme.eu/ro/details/smd0805-330r/rezistente-smd-0805/royal-ohm/0805s8j0331t5e/) | SMD0805-330R-5% | 1
1k | (LINK) (https://www.tme.eu/ro/details/smd0805-1k/rezistente-smd-0805/royal-ohm/0805s8j0102t5e/) | SMD0805-1K-5% | 2
510k | (LINK) (https://www.tme.eu/ro/details/smd0805-510k/rezistente-smd-0805/royal-ohm/0805s8j0514t5e/) | SMD0805-510K-5% | 2

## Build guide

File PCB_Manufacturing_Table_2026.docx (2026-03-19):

General info document for PCB manufacturing
No. | Item Name | File Name | | | | | | Info / Remarks / Notes
| BOARD
1 | Board Name / Number | PROIECT_APD_Ispas_pcb | | | | | | -
2 | Revision Date | 24 ianuarie 2026 | | | | | | -
3 | Board Size | 40 x 40 mm² | | | | | | -
4 | Board Quantity | 1 | | | | | | -
5 | Material / Dielectric Type | FR-4 | | | | | | -
6 | Board Thickness | 1.6 mm | | | | | | -
7 | Copper Thickness | 35 μm | | | | | | -
| LAYERS
8 | Number of Electrical Layers | 2 | | | | | | -
9 | Copper Layer TOP | TOP.art | | | | | | -
10 | Copper Layer BOTTOM | BOTTOM.art | | | | | | -
11 | Copper GND Plane | - | | | | | | -
12 | Copper PWR Plane | - | | | | | | -
13 | Copper INNER 1 | - | | | | | | -
14 | Copper INNER 2 | - | | | | | | -
15 | Solder Mask TOP | SMTOP.art | | | | | | -
16 | Solder Mask BOTTOM | SMBOT.art | | | | | | -
17 | Solder Paste TOP | SPTOP.art | | | | | | -
18 | Solder Paste BOTTOM | - | | | | | | -
19 | Peelable Mask TOP | - | | | | | | -
20 | Peelable Mask BOTTOM | - | | | | | | -
21 | Silk Screen TOP | SSTOP.art | | | | | | -
22 | Silk Screen BOTTOM | - | | | | | | -
23 | Board Outline | included on all layers | | | | | | -
24 | Fabrication Drawing | FAB.art | | | | | | -
| MILLING & DRILLING
25 | Mill Drawing | - | | | | | | -
26 | Drill Drawing | Included in FAB.art | | | | | | -
27 | N.C. Drill (for both PH & NPH) | - | | | | | | -
28 | N.C. Drill / Plated Holes (PH) | 11 | | | | | | -
29 | N.C. Drill / Non-Plated Holes (PH) | - | | | | | | -
| FINISHING
30 | Panelisation | - | | | | | | -
31 | Electrical Test | - | | | | | | -
32 | Copper Finishing | x | HASL | | OSP | | | ENIG
33 | Board Outline Machining | | Routing | | Milling | | x | V-Cutting
34 | Final remarks | - | | | | -
